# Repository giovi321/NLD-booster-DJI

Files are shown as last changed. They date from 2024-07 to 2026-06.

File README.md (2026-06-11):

# NLD booster board installation guides for DJI drones and remote controllers

Step-by-step guides for fitting a No Limit Dronez (NLD) signal booster board into various DJI drones and remote controllers. Each guide covers the wiring, placement, and physical modifications needed for that specific device.

## Disclaimer

- I am not affiliated with NoLimitDronez or any related entity. These guides are for informational purposes only.
- Everything you do based on this information is entirely at your own risk. I take no responsibility for damage, legal issues, or safety problems resulting from following these guides or modifying your devices in any way.
- Check your local laws before modifying or operating drones. In many jurisdictions, using a signal booster on a drone is regulated or prohibited.
- Read the safety rules below before you open anything.

## Safety rules

**Never power the booster without cooling.** In flight, the drone's airflow handles cooling automatically. On the bench there is no airflow, and the module will burn. Use a fan when bench testing.

**Never power the module without both signal connections in place.** The antenna output and the signal input must both be connected before powering on.

**Insulate every solder joint.** A bare joint shorting against the chassis at 120m altitude is not something you want to discover mid-flight.

**Use the right adhesive.** Several steps require thermally conductive, electrically insulating silicone adhesive. Using the wrong material can cause heat buildup or shorts.

**Handle IPEX connectors carefully, especially IPEX4.** They are very fragile and time-consuming to replace if damaged.

## Available guides

**Remote controllers**
- [DJI RC2](RC2_and_RC.md) (also applicable to the DJI RC)
- [DJI RC-N1](RC-N1.md)

**Drones**
- [DJI Air 3](Air_3.md)
- [DJI Mini 4 Pro](Mini_4_Pro.md)
- [DJI Mini 2](Mini_2.md)

**3D-printable cases for external mounting**
- [External installation cases](Cases%203D/readme.md) — use these if there is no room to fit the booster inside the drone

## What comes in the NLD kit

When ordered for the devices covered in this repo, the kit contains:

- 1x booster board for the remote (IPEX1 connectors)
- 1x booster board for the drone (IPEX4 connectors)
- 1x IPEX1 cable
- 1x IPEX4 cable
- 1x step-up module (converts any voltage above 1V to 5V)
- 1x step-down module (converts any voltage below 20V to 5V)

Other devices may need different connectors.

## How the installation works

The procedure is the same across all devices, though the order and specific details vary by device:

1. Solder the step-up or step-down board to the booster board (power connections only).
2. Connect the step-up or step-down board directly to the device's battery. Direct battery connection matters because a random PCB pad might show the correct voltage but not supply enough current.
3. Connect the EN pin of the step-up or step-down board to a 3.3-5V point that is only live when the device is powered on. This keeps the booster off when the device is off. On drones, this step is usually only needed if the battery connection point is always-on.
4. Connect the device's antenna to the "ANT" connector on the booster board. This is the signal output.
5. Connect the booster board's signal input to the drone or RC mainboard. This is the signal source the booster amplifies.

## License

The content of this repository is licensed under the [WTFPL](http://www.wtfpl.net/).

```
Copyright © 2024 giovi321
This work is free. You can redistribute it and/or modify it under the
terms of the Do What The Fuck You Want To Public License, Version 2,
as published by Sam Hocevar. See the LICENSE file for more details.
```

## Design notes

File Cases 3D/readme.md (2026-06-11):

# 3D-printable cases for external booster module installation

These cases let you mount the booster module and step-down module on the outside of the drone, typically velcroed to the top. Use them when there is no room to fit the booster internally.

All cases should be printed in ABS. It handles heat better than PLA, which matters here since the booster module generates real heat under load.

## Requirements common to all cases

- Velcro strap to attach the case to the drone
- 2mm neoprene strips
- Female IPEX4 to female IPEX4 cable, 10-15cm (available on AliExpress)
- A small amount of silicone to seal the cable entry holes

Plastic cases also need:
- 4x M2x4x3.2 threaded inserts
- 4x M2x6 screws
- Raspberry Pi-style heatsinks (available on [AliExpress](https://www.aliexpress.com/item/1005007485448259.html) or [Amazon](https://www.amazon.com/dp/B07YR6M6F6/)):
  - 4x 14x14mm heatsinks
  - 1x 14x9mm heatsink

## Available cases

### Plastic case

The simplest option. Designed primarily for the DJI Mini 2 but compatible with any drone.

[Plastic case STL](https://github.com/giovi321/NLD-booster-DJI/blob/main/Cases%203D/NLD%20booster%20board%20plastic%20case_v3.stl)



### Plastic case with built-in battery

If you do not want to solder anything to the drone, this is the option. The battery inside the case powers the booster independently.

[Plastic case with battery STL](https://github.com/giovi321/NLD-booster-DJI/blob/main/Cases%203D/NLD%20booster%20board%20plastic%20case%20battery_v1.stl)

Additional parts needed:
- USB Type-C female breakout board (available on [AliExpress](https://www.aliexpress.com/item/1005004861928502.html))
- 403040 LiPo 3.7V battery, at least 500mAh



### Aluminum case

The most capable option. Fully waterproof, with the heatsink built into the case walls, so no separate heatsink is needed. It does need to be CNC machined or metal 3D printed, which costs more than plastic.

Apply thermal paste or thermal adhesive to bond the booster board to the inside of the case.

[Aluminum case STL](https://github.com/giovi321/NLD-booster-DJI/blob/main/Cases%203D/NLD%20booster%20board%20aluminum%20case_v2.stl)



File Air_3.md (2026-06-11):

# Installing the NLD booster board on a DJI Air 3

Disassembly is not covered here. [This video](https://www.youtube.com/watch?v=8k8JhMTr9xc) is a good starting point.

## Tools needed

- Soldering iron with a thin tip, capable of reaching 400°C
- Thermally conductive, electrically insulating silicone adhesive (something like this):



- Multimeter
- Torx and Phillips screwdrivers
- Sharp blade to scrape solder mask off PCB pads
- Optional but useful: plastic pry tools for opening electronics:



## Before you start

- Protect all solder joints with thermally conductive, electrically insulating silicone adhesive.
- Use hot glue on antenna connections so they are easy to remove later if needed.
- No heatsink is needed on the Air 3. The drone's cooling fan sits directly above where the booster module mounts, so airflow handles it in flight.
- The battery connector pads on the core board are covered with solder mask. Scrape them with a blade before attempting to solder.
- Route signal cables so they do not pass over or under the booster board. Interference from the board can heavily degrade signal.

## Installation

### Step 1: Remove the core board

Disassemble the bottom of the drone to expose the core board. The gimbal does not need to come out.

Remove the glue holding the antenna connectors in place. Squeeze the hardened glue gently with pliers to separate it from the connectors without putting stress on the connectors themselves. Do not pull directly on the connectors.



Use pliers to unplug each connector by applying upward leverage from underneath.



Remove all core board screws and lift the board out.



### Step 2: Connect power

Solder the step-down module to the booster board.



Identify the battery connector pads. You need the first and the last connector (polarity shown in the picture: black = negative, red = positive).



Scrape the pads with a blade to expose clean metal. At 350°C, with some patience, the solder will bond. Do not overheat. Cover the finished joints with silicone adhesive.

Solder the battery wires to the step-down module.



### Step 3: Mount the booster and step-down modules

Optional but worth doing: cut a square of metal from a plastic pry tool and glue it to the drone's plastic body beneath the cooling fan, then cover it with Kapton tape. This gives a better thermal surface.

Apply silicone adhesive to the area of the drone body directly below the cooling fan.



Press the step-down module and booster module into the adhesive. Two things to keep in mind:
- The booster module should sit as close to the gimbal as possible.
- Leave enough space between the step-down module and the booster module so the fan's foam seal can fit between them.



### Step 4: Connect the antenna

From testing, no antenna consistently outperforms the others. I used the black antenna cable marked "1" on the core board.



Connect that cable to the "ANT" connector on the booster board.



Connect the IPEX cable included with the booster board to the other connector on the booster board. Route it around the board without crossing it and let the free end hang on the same side of the drone as the other antenna cables (follow the red line in the picture).



### Step 5: Reassemble

Put the core board back in place. Before closing up:
- Make sure signal and antenna cables do not cross the booster board.
- Reconnect all ribbon cables.
- Reconnect all antenna cables except the one plugged into the booster board.
- Connect the free end of the IPEX cable from the booster board to the empty connector on the core board, the one marked "1".



## Results

A quick RF meter test confirms the booster works well:
- Left reading: boosted antenna output, **-27.8 dBm**
- Right reading: unboosted antenna output, **-41.2 dBm**



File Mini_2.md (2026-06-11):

# Installing the NLD booster board on a DJI Mini 2

Disassembly is not covered here. [This video](https://www.youtube.com/watch?v=C_9mIduaoMY) covers both the drone and remote.

## Tools needed

- Soldering iron with a thin tip, capable of reaching 400°C
- Thermally conductive, electrically insulating silicone adhesive (something like this):



- Multimeter
- Phillips screwdrivers
- Sharp blade
- 120-grit sandpaper
- Metal pry tool to use as a sanding block:



- Optional but useful: plastic pry tools for opening electronics:



## Additional parts needed

- 15cm female IPEX4 to female IPEX4 extension cable (available on AliExpress)
- 14x15x4mm heatsink (available on Amazon)

## Before you start

- Protect all solder joints with thermally conductive, electrically insulating silicone adhesive.
- Use hot glue on antenna connections so they are easy to remove later.
- Fit heatsinks on both boards. The ones included in the NLD kit work, but better options are available on Amazon.
- Battery connector pads need scraping with a blade before solder will stick.
- Signal cables must not run over or under the booster board. The interference can heavily degrade signal. The pictures do not always show this correctly. Do it right regardless.

## Installation

### Step 1: Cut the heatsink window

With the drone disassembled, use a cutter to cut a square opening in the top cover, sized to match the heatsink exactly.



Use the metal pry tool with sandpaper attached to clean up the edges and get the fit right.



Stick the heatsink to the booster board, then glue the booster board to the inside of the top cover using silicone adhesive, so the heatsink sits flush in the opening.



The result should look like this:



### Step 2: Mount the step-down module

Stick the step-down board to the plastic shell at the rear of the drone. Do not place it on top of the GPS antenna, which is the large component highlighted in red in the picture below.



### Step 3: Connect power

Remove the core board to access the ESC board. Connect the step-down module to the three pads shown below:
- GREEN: ground (black wire)
- RED: positive (red wire)
- YELLOW: EN pin



What the board looks like installed on the drone:



For the battery connector pads (green and red), scrape them with a blade first and use 400°C. The solder mask is stubborn.

### Step 4: Connect the antennas

The internal antenna cable running through the drone is too long once the booster is installed. Replace it with the new 15cm IPEX4 female-to-female cable, routed through the exact same path as the original (shown as the green line below).



Then:
- Connect the "ANT" connector on the booster board to the grey cable coming out of the drone arm. That cable is the external antenna.
- Connect the remaining IPEX1 connector on the booster board to the core board using the new 15cm cable.

Signal cables must not run over or under the booster board.

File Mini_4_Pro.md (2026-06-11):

# Installing the NLD booster board on a DJI Mini 4 Pro

Disassembly is not covered here. [This video](https://youtu.be/rLTtYpftaGs?feature=shared) is a good reference.

## Tools needed

- Soldering iron with a thin tip, capable of reaching 400°C
- Thermally conductive, electrically insulating silicone adhesive (something like this):



- Multimeter
- Torx and Phillips screwdrivers
- Sharp blade
- Optional but useful: plastic pry tools for opening electronics:



## Before you start

- Protect all solder joints with thermally conductive, electrically insulating silicone adhesive.
- Use hot glue on antenna connections so they are easy to remove later.
- Fit heatsinks on both boards. The NLD-supplied ones work fine; better options are on Amazon.
- Battery connector pads need scraping before solder will stick.
- Signal cables must not run over or under the booster board.

## Installation

### Step 1: Access the battery connector

Remove the main board and obstacle avoidance cameras from the top of the drone.

Remove the three Torx screws holding the battery connector PCB in place. You do not need to remove the connector entirely. With the obstacle avoidance cameras out, push the small battery connector PCB up slightly from above using tweezers. On the back of that PCB, peel up the adhesive plastic layer to expose the connector pads.

### Step 2: Solder to the battery connector

Scrape the connector pads with a blade to remove the solder mask. At 350°C, with some patience, the solder will bond. Do not overheat. Solder wires to the correct pads following the Mini 4 Pro battery pinout:



Cover the finished joints with thermally conductive silicone adhesive.

### Step 3: Wire the step-down converter

Connect the step-down converter to the battery wires and to the booster board.

Connect the EN pin of the step-down converter to the inductance labeled "2R2" as shown below, then cover with silicone adhesive.



Glue the step-down converter to the top of the obstacle avoidance sensor cluster using silicone adhesive.



### Step 4: Connect the antenna

Disconnect the antenna connector labeled "ANT0". It has the longest cable of the group, which makes it the easiest to route to the booster board. Any antenna connector will work as long as the cable can reach.



Connect the ANT0 cable to the booster board's signal input. Connect the booster board's "ANT" output to the core board connector that ANT0 was removed from.

### Step 5: Mount the booster board

Glue the booster board to the aluminum section between the GPS antenna and the obstacle avoidance sensor cluster, using silicone adhesive. The NLD-supplied heatsink goes under the booster board, between it and the aluminum surface.





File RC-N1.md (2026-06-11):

# Installing the NLD booster board on a DJI RC-N1

Disassembly is not covered here. [This video](https://www.youtube.com/watch?v=pexzuVWaB08) is a good starting point.

## Tools needed

- Soldering iron with a thin tip, capable of reaching 400°C
- Thermally conductive, electrically insulating silicone adhesive (something like this):



- Multimeter
- Phillips screwdrivers
- Optional but useful: plastic pry tools for opening electronics:



## Additional parts needed

- NLD heatsink

## Before you start

- Protect all solder joints with thermally conductive, electrically insulating silicone adhesive.
- Use hot glue on antenna connections so they are easy to remove later.
- Fit a heatsink on the booster board. The NLD-supplied one works fine.
- Signal cables must not run over or under the booster board.

## Installation

With the RC disassembled:
- Remove the aluminum heatsink from the remote.
- Remove the transparent plastic cover and set it aside. It does not go back in.

### Step 1: Connect power

Solder the step-up module to the RC board using the three pads shown below:
- GREEN: positive 5V output (red wire of the step-up module)
- BLUE: ground (black wire of the step-up module)
- YELLOW: EN pin



### Step 2: Connect the antenna

- Connect the white antenna cable to the "ANT" connector on the booster board.
- Connect the remaining IPEX1 connector on the booster board to the antenna connector on the RC board.



### Step 3: Secure everything

- Wrap the step-up board in heat shrink tubing to insulate it.
- Fit the NLD heatsink to the booster board, leaving about 8mm of board exposed at one end. That exposed section is what gets glued directly to the aluminum frame of the RC.



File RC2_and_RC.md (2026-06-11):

# Installing the NLD booster board on a DJI RC2

This guide also applies to the DJI RC. Disassembly is not covered here. [This video](https://youtu.be/dhpUh3fc1Z8) was made for the RC but works for the RC2 as well.

## Tools needed

- Soldering iron with a thin tip, capable of reaching 370°C
- Thermally conductive, electrically insulating silicone adhesive (something like this):



- Multimeter
- Hex and Phillips screwdrivers
- Optional but useful: plastic pry tools for opening electronics:



## Before you start

- Protect all solder joints with thermally conductive, electrically insulating silicone adhesive.
- Use hot glue on antenna connections so they are easy to remove later.
- Fit heatsinks on both boards. The NLD-supplied ones work; better options are on Amazon.
- Signal cables must not run over or under the booster board.

## Installation

With the remote disassembled, carefully remove the fan assembly and aluminum heatsink without disturbing the thermal paste on the heatsink.

### Step 1: Connect power

The easiest access to power is the left battery (orient yourself with the antennas facing up). Right next to the battery connector are two small pads: one square, one circular. Solder positive and negative to these pads, connect to the step-up converter, and cover with silicone adhesive. The pads are not masked, so no scraping is needed.



Connect the EN pin of the step-up converter to the top-most pin of the ribbon connector for the C1/C2 buttons on the back of the remote. Solder and cover with silicone adhesive.



### Step 2: Connect the antenna

From testing, the choice of antenna makes no measurable difference. I used one of the external antennas because I am planning to add SMA connectors later for interchangeable externals.

There is a cable length problem to solve first. The right antenna's cable is too short to reach the booster board, which mounts on the left side of the fan. The left antenna is labeled "G" and appears to be the GPS antenna, so it cannot be used for the booster.

The solution is to swap the two external antennas. Disconnect both (labeled "G" and "ANT0") from the PCB, remove them from the body with pliers, and reinstall them on opposite sides. The right antenna goes into the left slot and vice versa. When reinserting, pay attention to orientation. The antennas do not rotate 360 degrees and will only slide into the hole correctly when aligned properly.



Connect the cable of the antenna now on the left side to the booster board and finish all the power connections.

### Step 3: Physical modifications

Cut the piece of plastic shown below from the back of the remote body to make room for the booster board.



Cut the piece shown below from the fan duct assembly. This improves airflow and also prevents the board from covering a screw once it is glued to the heatsink, which would make future disassembly impossible.



### Step 4: Secure the board

Wrap the step-up converter in heat shrink tubing and place it near the buzzer at the top of the remote.

Glue the booster board to the aluminum heatsink in the section not covered by the fan assembly, using thermally conductive silicone adhesive. Signal cables must not run over the booster board.



## Optional: add a dedicated cooling fan

After several weeks of use, I fitted an additional fan and the thermal performance improved noticeably. The booster module runs better with active cooling.

The fan I used is a 1703 blower from SUNON (available on AliExpress), paired with a 15x15x4mm heatsink. It fits the space well and draws only 35mA.



I designed a 3D-printable mount for the fan. It is not strictly necessary but makes the installation much easier. I printed mine in TPU, which is more forgiving on tolerances when closing the remote back up.

[Fan support STL file](https://github.com/giovi321/NLD-booster-DJI/blob/main/Fan%20support%20for%20DJI%20RC2_v2.stl)

**Installation:**

1. Remove the screw holding the original fan and heatsink in place, fit the printed mount, and screw everything back together.
2. Use cyanoacrylate to glue the fan to the mount.



3. Apply two strips of silicone adhesive to the heatsink surface. These serve two purposes: they lift the booster board slightly to allow airflow underneath, and they hold the board in place under the pressure of the back cover when the remote is closed.



4. Stick the heatsink to the back of the booster board at the top-left corner.



5. Connect the fan ground (black wire) to the ground output of the step-up converter.
6. Connect the fan 3.3V supply (red wire) to the EN pin of the step-up converter. The EN pin provides a 3.3V signal and 35mA is low enough that drawing from it causes no problems.
7. Place the booster board on the two silicone adhesive strips and close the remote.



The fan turns on as soon as the remote powers up. It is audible, but the cooling benefit is real.

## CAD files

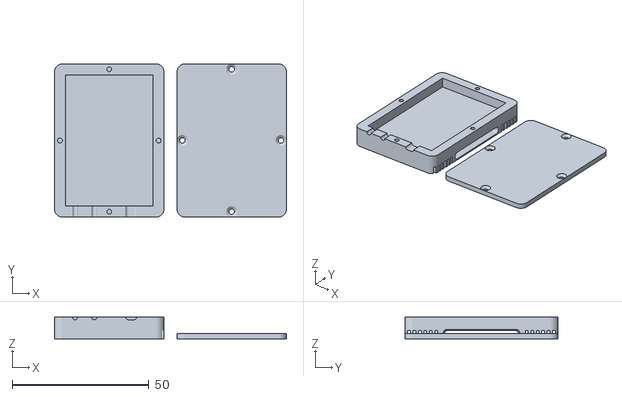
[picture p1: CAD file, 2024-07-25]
Cases 3D/NLD booster board aluminum case_v2.stl
84.7 x 56.0 x 8.00

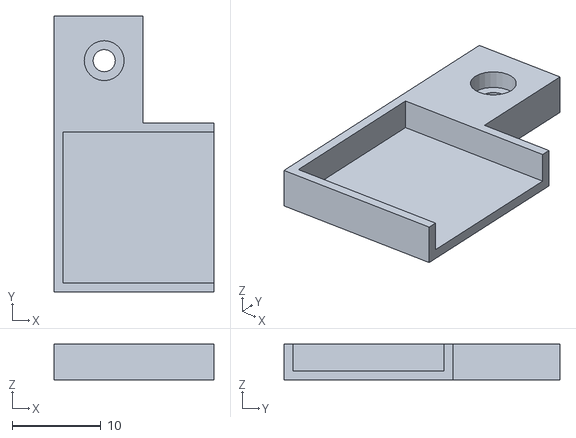
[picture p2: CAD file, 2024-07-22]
Fan support for DJI RC2_v2.stl
18.0 x 31.0 x 4.00

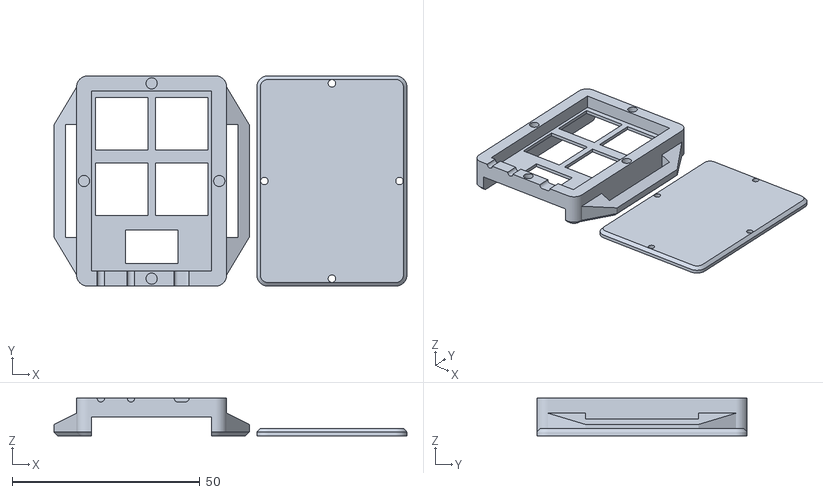
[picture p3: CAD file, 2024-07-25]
Cases 3D/NLD booster board plastic case_v3.stl
94.0 x 56.0 x 10.0

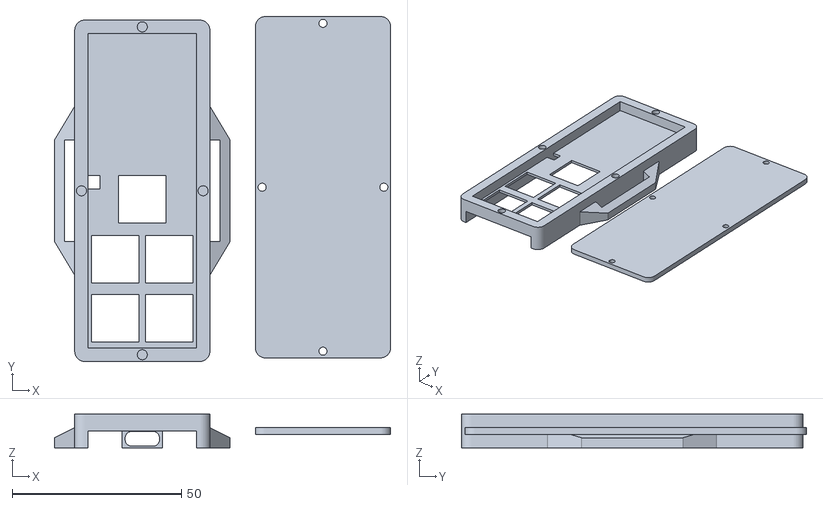
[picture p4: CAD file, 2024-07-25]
Cases 3D/NLD booster board plastic case battery_v1.stl
99.4 x 102.1 x 10.0
